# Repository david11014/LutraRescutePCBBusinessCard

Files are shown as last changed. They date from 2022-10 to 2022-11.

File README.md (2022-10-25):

# LutraRescutePCBBusinessCard

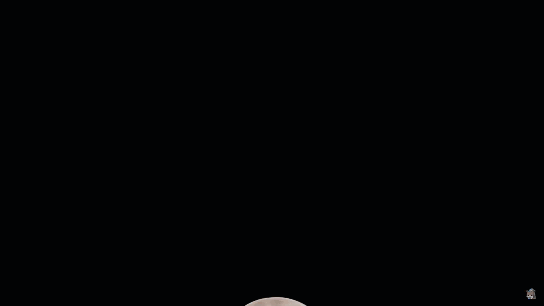
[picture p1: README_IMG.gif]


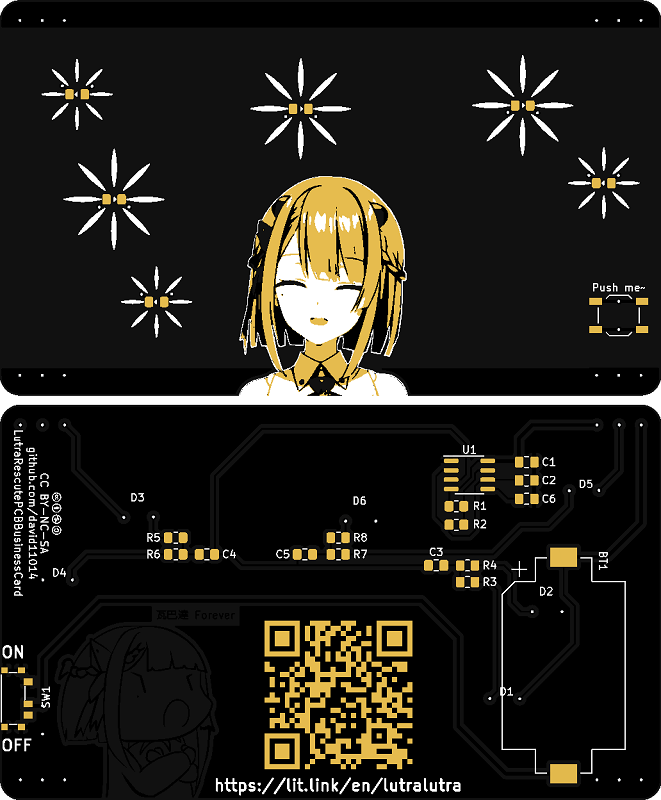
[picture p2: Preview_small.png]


# Intro

瀕臨絕種團露恰露恰的 PCB 名片，靈感來自以下直播內容
[【魔女之家#2】見習小魔女水獺的新家大冒險🍻【露恰露恰．Vtuber】](https://youtu.be/RvgKsK7jW5E?t=4198)

感謝[春魚工作室](https://t.co/JhnwOmfZGn)與[里歐](https://twitter.com/leo_chen0912/status/1580262135908945920)授權使用圖片

This is a PCB business card of LutraLutra, the idea is inspired by the blow live video [【魔女之家#2】見習小魔女水獺的新家大冒險🍻【露恰露恰．Vtuber】](https://youtu.be/RvgKsK7jW5E?t=4198).

Thanks to [春魚工作室](https://t.co/JhnwOmfZGn) and [里歐](https://twitter.com/leo_chen0912/status/1580262135908945920) for the permission to use image.

# BOM
|Ref |Qnty |Value |Footprint |Description |Vendor |
|---|-----|---|---|---|---|
|BT1, |1 |Battery_Cell |Battery:BatteryHolder_Keystone_1060_1x2032 |Single-cell battery |https://ok.100y.com.tw/Goods/52684 |
|C1, |1 |0.1uF |Capacitor_SMD:C_0805_2012Metric_Pad1.18x1.45mm_HandSolder  |Unpolarized capacitor |https://ok.100y.com.tw/Goods/99587 |
|C2, C3, C4, C5, |4 |10uF |Capacitor_SMD:C_0805_2012Metric_Pad1.18x1.45mm_HandSolder  |Unpolarized capacitor |https://ok.100y.com.tw/Goods/42857 |
|C6, |1 |0.001uF |Capacitor_SMD:C_0805_2012Metric_Pad1.18x1.45mm_HandSolder  |Unpolarized capacitor |https://ok.100y.com.tw/Goods/124188|
|D1, D2, D3, D4, D5, D6  |6 |LED |Img:LED_0805_2012Metric_Pad1.15x1.40mm_HandSolder |Light emitting diode |https://ok.100y.com.tw/Goods/99164 |
|R1, R2, |2 |100K |Resistor_SMD:R_0805_2012Metric_Pad1.20x1.40mm_HandSolder |Resistor |https://ok.100y.com.tw/Goods/123451|
|R3, R4, R5, R6, R7, R8, |6 |2K |Resistor_SMD:R_0805_2012Metric_Pad1.20x1.40mm_HandSolder |Resistor |https://ok.100y.com.tw/Goods/123312|
|SW1, |1 |SW_DPDT_x2 |Img:Switch_MSK-01A |Switch, dual pole double throw, separate symbols|https://ok.100y.com.tw/Goods/139685|
|SW2, |1 |SW_Push |Button_Switch_SMD:SW_SPST_TL3342 |Push button switch, generic, two pins |https://ok.100y.com.tw/Goods/98045 |
|U1, |1 |LMC555CM/NOPB|Package_SO:SOIC-8_3.9x4.9mm_P1.27mm |CMOS Timer, 555 compatible, SOIC-8 |https://ok.100y.com.tw/Goods/56713 |

# License

<br />本著作係採用<a rel="license" href="http://creativecommons.org/licenses/by-nc-sa/4.0/">創用 CC 姓名標示-非商業性-相同方式分享 4.0 國際 授權條款</a>授權.

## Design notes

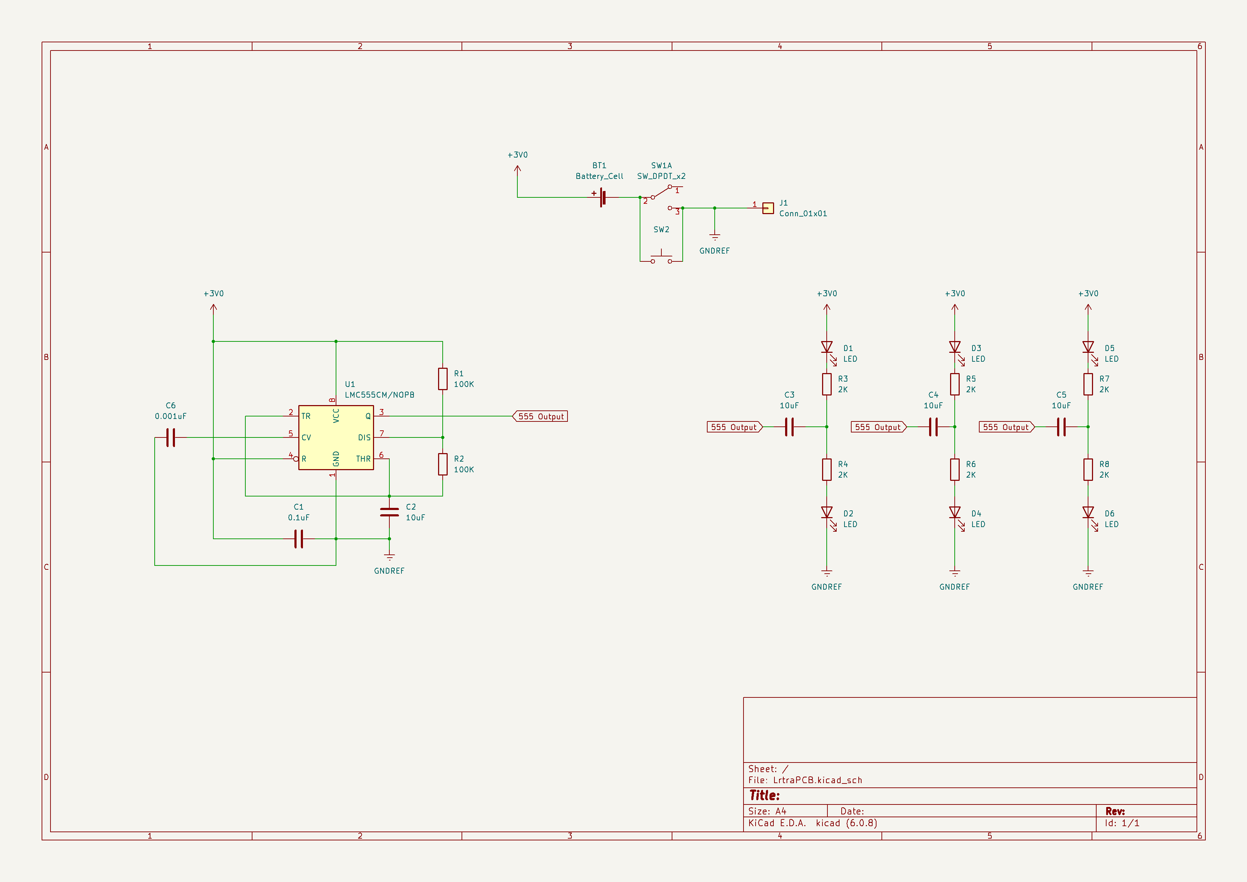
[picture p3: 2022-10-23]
LrtraPCB_kicad_sch.png

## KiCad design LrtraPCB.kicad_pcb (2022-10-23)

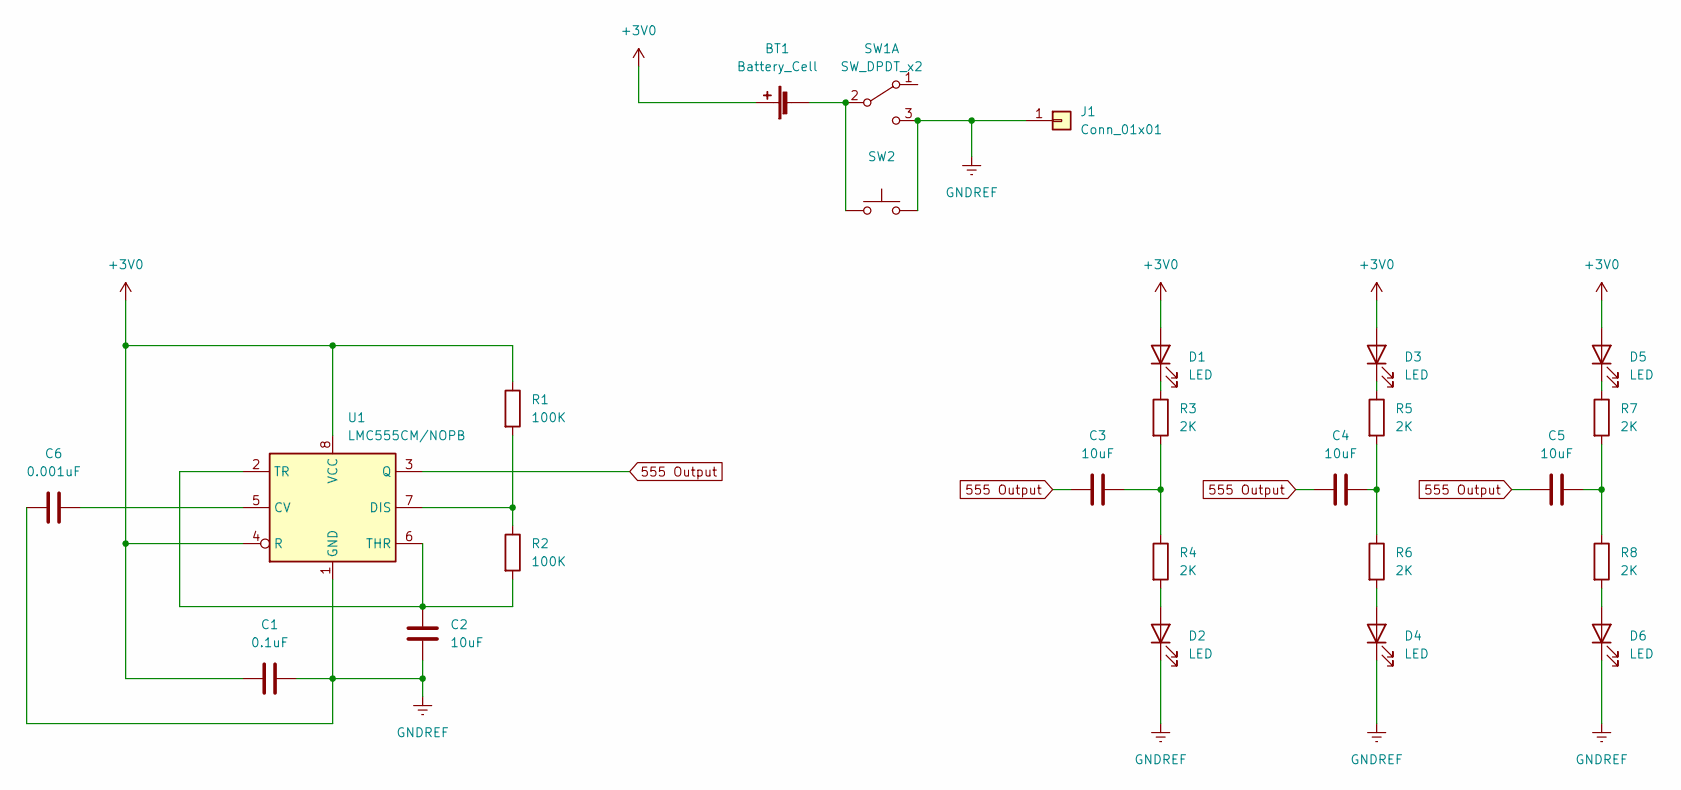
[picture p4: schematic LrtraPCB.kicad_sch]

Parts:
BT1: Battery_Cell; BatteryHolder_Keystone_1060_1x2032
C1: 0.1uF; C_0805_2012Metric_Pad1.18x1.45mm_HandSolder
C2, C3, C4, C5: 10uF; C_0805_2012Metric_Pad1.18x1.45mm_HandSolder
C6: 0.001uF; C_0805_2012Metric_Pad1.18x1.45mm_HandSolder
D1, D4, D5: LED; LED_0805_2012Metric_Pad1.15x1.40mm_HandSolder_Flower_small
D2, D3, D6: LED; LED_0805_2012Metric_Pad1.15x1.40mm_HandSolder_Flower
J1: Conn_01x01; Lutra_QRCode
R1, R2: 100K; R_0805_2012Metric_Pad1.20x1.40mm_HandSolder
R3, R4, R5, R6, R7, R8: 2K; R_0805_2012Metric_Pad1.20x1.40mm_HandSolder
SW1: SW_DPDT_x2; Switch_MSK-01A
SW2: SW_Push; SW_SPST_TL3342
U1: LMC555CM/NOPB; SOIC-8_3.9x4.9mm_P1.27mm

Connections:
555 Output: C3.1, C4.1, C5.1, U1.3 (Q)
+3V0: BT1.1 (+), C1.2, D1.2 (A), D3.2 (A), D5.2 (A), R1.1, U1.4 (R), U1.8 (VCC)
GNDREF: C1.1, C2.2, C6.2, D2.1 (K), D4.1 (K), D6.1 (K), J1.1, SW1.3 (C), SW1.4 (A), SW2.2, U1.1 (GND); also elsewhere on the board
unnamed 3: BT1.2 (-), SW1.2 (B), SW2.1; also elsewhere on the board
unnamed: C2.1, R2.2, U1.2 (TR), U1.6 (THR)
unnamed: C3.2, R3.2, R4.1
unnamed: C4.2, R5.2, R6.1
unnamed: C5.2, R7.2, R8.1
unnamed: C6.1, U1.5 (CV)
unnamed: D1.1 (K), R3.1
unnamed: D2.2 (A), R4.2
unnamed: D3.1 (K), R5.1
unnamed: D4.2 (A), R6.2
unnamed: D5.1 (K), R7.1
unnamed: D6.2 (A), R8.2
unnamed: R1.2, R2.1, U1.7 (DIS)

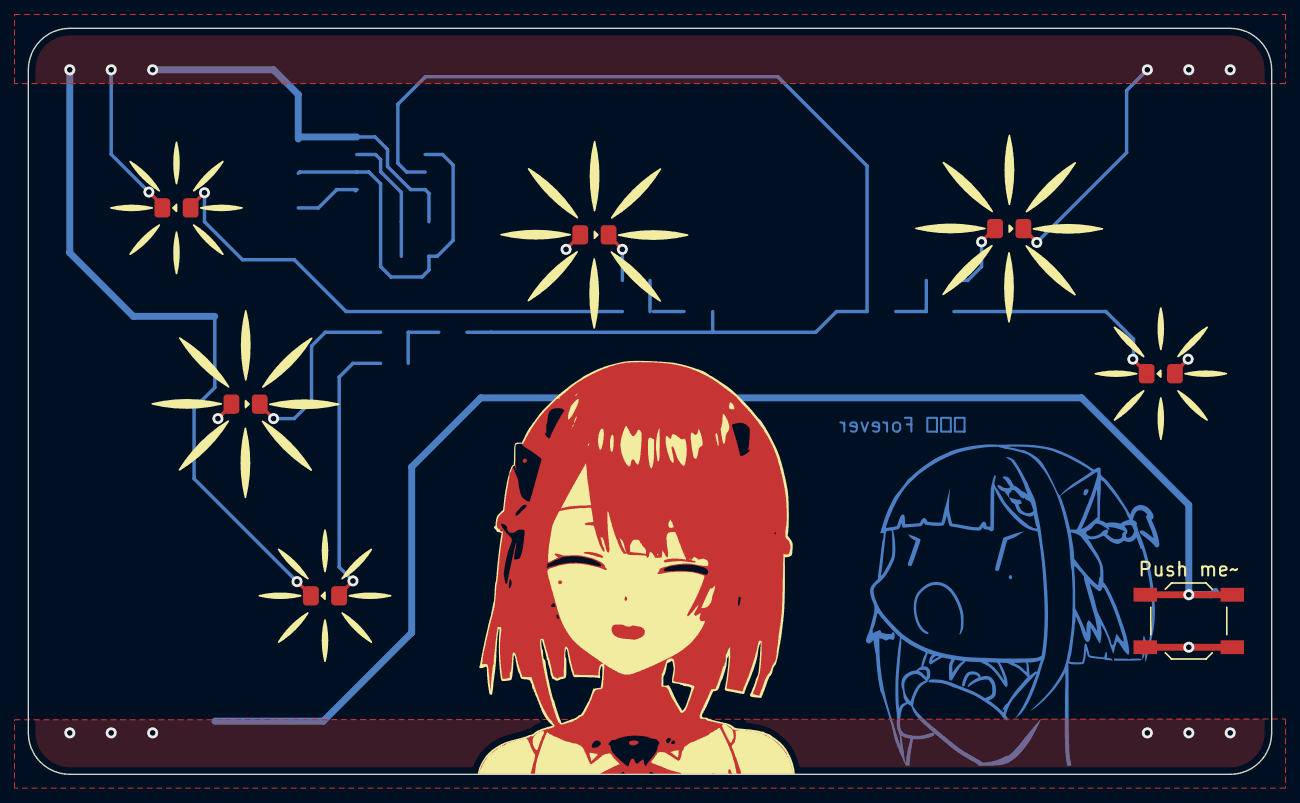
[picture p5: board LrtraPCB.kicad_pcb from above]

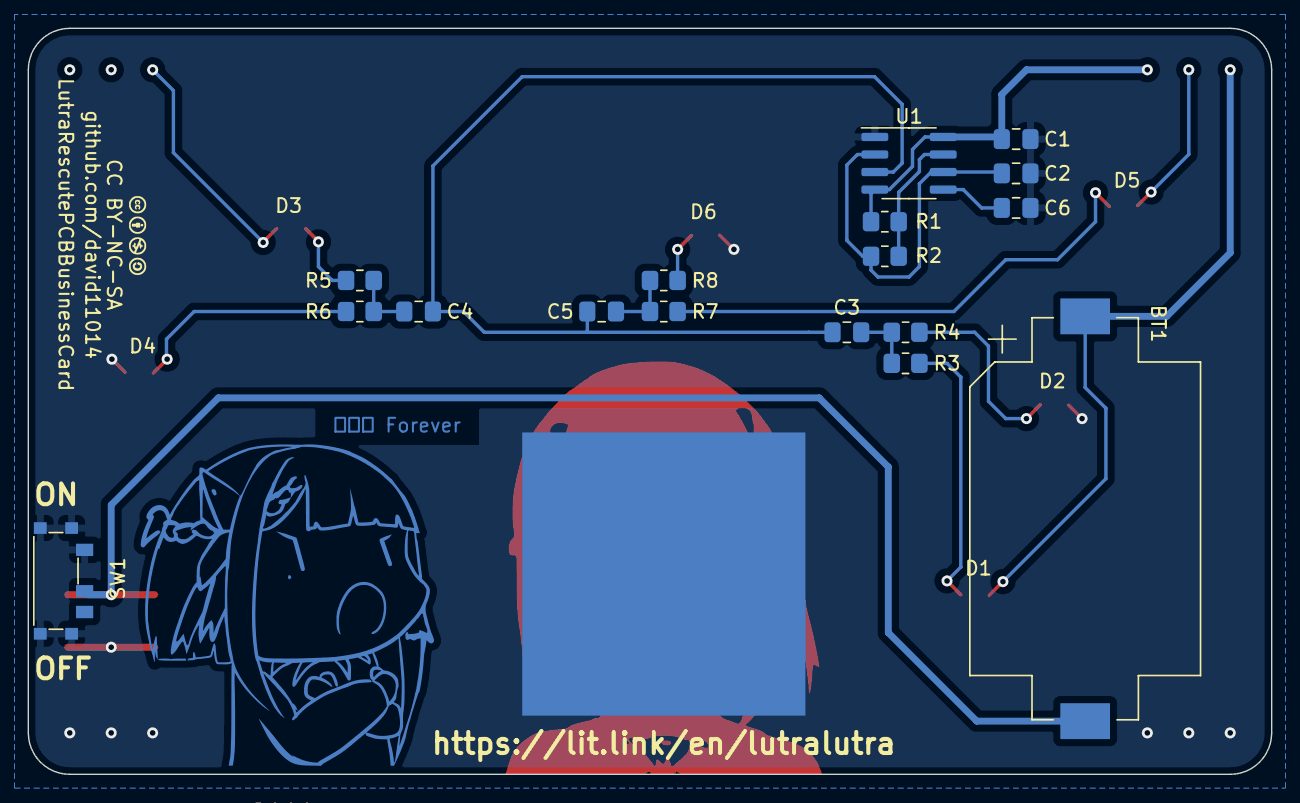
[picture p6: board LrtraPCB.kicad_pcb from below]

Board: 2 copper layers, 90.0 x 54.0 mm, 26 parts (19 on the bottom side), 16 nets.

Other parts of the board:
LutraRescutePCBBusinessCard: CC-BY-NC-SA
Push me~: SW_Push; SW_SPST_TL3342
https://lit.link/en/lutralutra: Conn_01x01; Lutra_QRCode

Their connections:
GNDREF: Push me~.2, https://lit.link/en/lutralutra.1; also elsewhere on the board
unnamed 3: Push me~.1; also elsewhere on the board

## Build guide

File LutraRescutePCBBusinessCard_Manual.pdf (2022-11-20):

# 露恰 PCB 名片組裝說明書

## 電路原始檔案

https://github.com/david11014/LutraRescutePCBBusinessCard

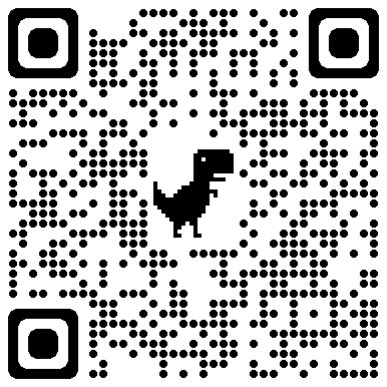
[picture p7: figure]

## 焊接教學

組裝時需要使用電烙鐵把電子零件焊接在電路板上，如果不會焊接電路的話，先參考下方兩支教學影片， 了解如何焊接電路板，第一個基礎電路焊接教學，第二個是表面貼片元件(SMD)焊接教學

教學 | QR code | 網址
焊接基礎教學 | | https://youtu.be/UUIHBjsaMeM (https://youtu.be/UUIHBjsaMeM)

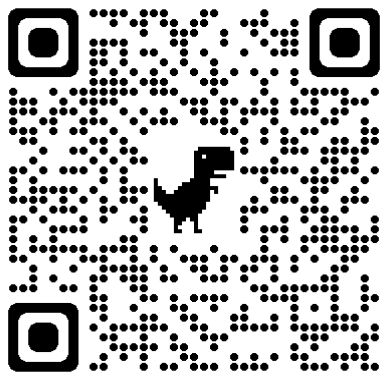
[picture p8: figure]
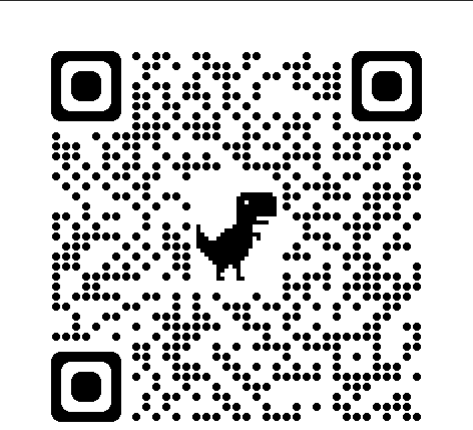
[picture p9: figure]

SMD 焊接教學 | | https://youtu.be/fYInlAmPnGo?t=437 (https://youtu.be/fYInlAmPnGo?t=437)

## 不用知道原理也知道怎麼看電路圖焊接

觀察電路板上的文字，可以發現在金色的焊點附近，有標示英文與數字的組合，這個是零件 的編號。英文表示零件的種類，數字為流水號。另外白色直線則是標示零件的輪廓。

觀察電路圖，看到每個符號的旁邊有一個同樣格式的編號，表示電路板的對應位置要放上這 個零件。另外一行文字則是標記這個零件的型號，只要照著編號把零件焊到對應的位置就完 成拉~~~。也可以參考組裝圖的說明，內附精美圖片標示零件的擺放位置⎝(ﾟ 。∀ )⎠

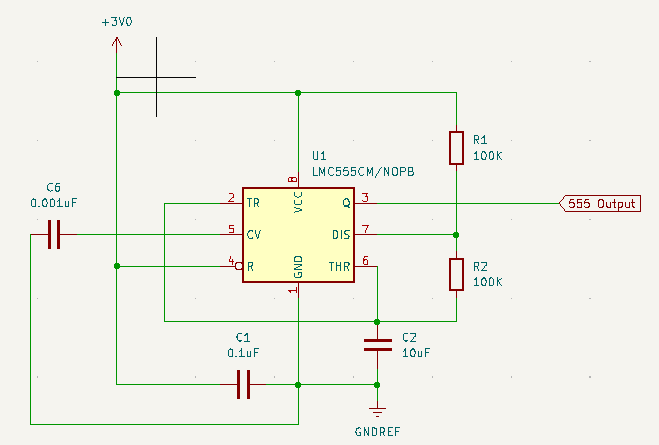
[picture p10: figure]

基本元件可以參考以下表格

元件名稱 | 種類標記 | 圖示 | 長怎樣 | 電路板上的圖案
開關 | SW
按鍵開關 | SW

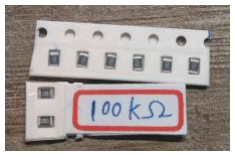
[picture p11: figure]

電阻 | R
電容 | C

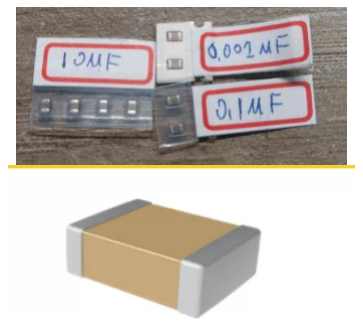
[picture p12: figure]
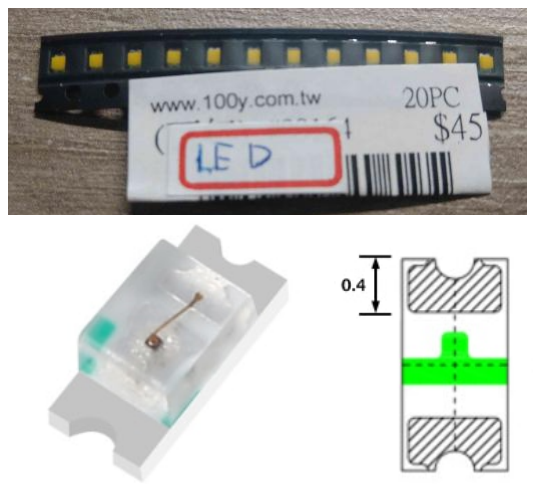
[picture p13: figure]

LED | D | 背面 T 字形橫線部分是正極 | 三角形箭頭頂端是正 極
IC | U | | IC 上的圓點對齊左 上角

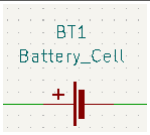
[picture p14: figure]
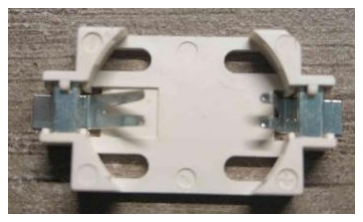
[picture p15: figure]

電池/電池盒 | BT

## 器材與材料

需要準備的器材如下

器材 | 數量 | 長怎樣 | 備註
電烙鐵 | 1 支 | | 30~40 瓦(W) 的即可
烙鐵架 | 1 組

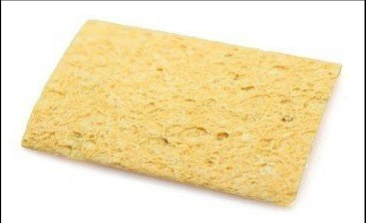
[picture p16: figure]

清潔海綿 | 1 片 | | 清潔烙鐵頭用
鑷子 | 1 支 | | 找尖端比較尖的，比 較好夾零件

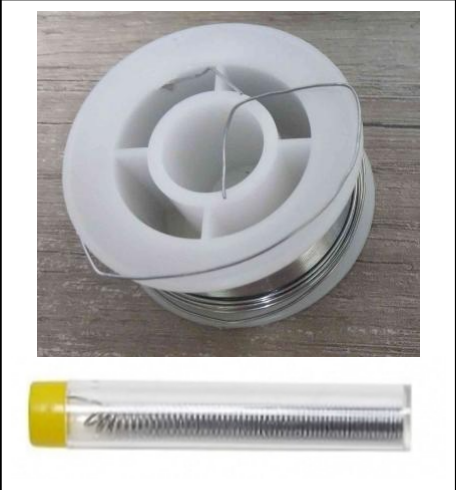
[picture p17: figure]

焊錫 | 1 捲 | | 建議選直徑 0.6 mm 以下的

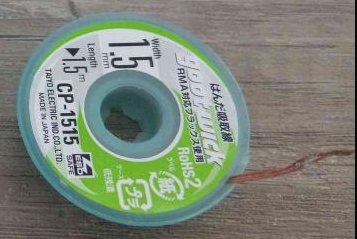
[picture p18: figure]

吸錫線 | 1 捲

請清點材料包有以下零件

註：電阻、電容、LED 的封裝大小為 0805 (0.08" x 0.05")

零件 | 型號 | 編號 | 數量
電池盒 | Battery_Cell | BT1 | 1
電容 | 0.1uF | C1 | 1
電容 | 10uF | C2, C3, C4, C5 | 4
電容 | 0.001uF | C6 | 1
LED | LED | D1, D2, D3, D4, D5, D6 | 6
電阻 | 100K | R1, R2 | 2
電阻 | 2K | R3, R4, R5, R6, R7, R8 | 6
開關 | SW_DPDT_x2 | SW1 | 1
按鍵開關 | SW_Push | SW2 | 1
555 計時器 | LMC555CM/NOPB | U1 | 1

## 組裝圖

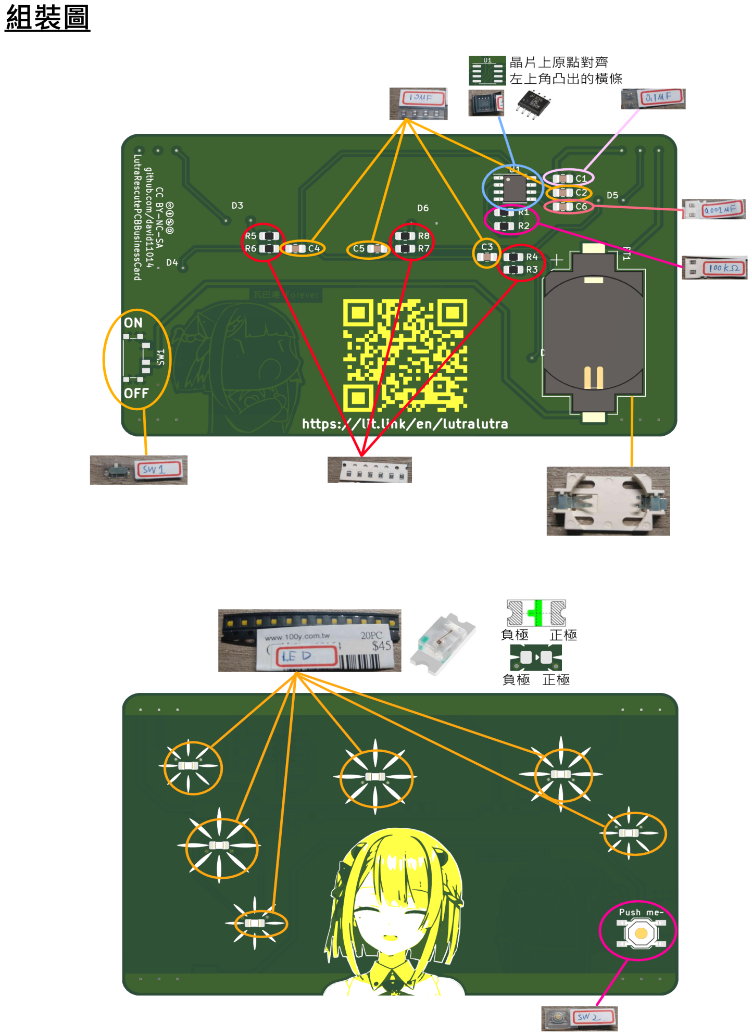
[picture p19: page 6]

## 電路圖

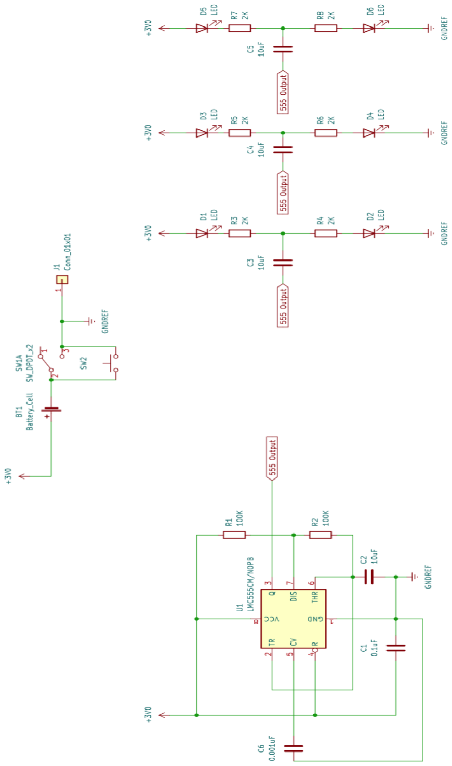
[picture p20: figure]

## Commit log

2022-10-23 [add] Add First version
    [LrtraPCB.kicad_pcb, LrtraPCB.kicad_sch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]
2022-10-23 [modify] modify sign
    [LrtraPCB.kicad_pcb]
2022-10-23 [modify] 更新鋪銅
    [LrtraPCB.kicad_pcb]
2022-10-23 [add] Add Gerbers file
    [LrtraPCB-B_Cu.gbr, LrtraPCB-B_Mask.gbr, LrtraPCB-B_Paste.gbr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]
2022-10-25 [Add] Add BOM Table

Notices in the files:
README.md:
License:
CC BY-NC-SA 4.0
